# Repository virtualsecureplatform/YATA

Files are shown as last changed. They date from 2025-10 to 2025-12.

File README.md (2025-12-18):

This repository is the artifact for the TCHES2026 paper; YATA: Yet Another TFHE Accelerator with Key Compression and Radix-8 NTT

# Directories
- YATA-RTL: RTL codes excluding NDA related things like SRAM IP and PLL. This also contains RTL-level simulations and some Python scripts we used for the design. 
- YATA-PCB: The KiCAD project for the evaluation board.
- YATA-script: Test\&Measurement and making graph scripts, we used to make the evaluation section of our paper. This also contains Equipment.md, the description of the measurement equipment we used.

# LICENSE
RTL is basically licensed under AGPLv3, except for the AsyncQueue, which originated from Rocketchip. 

PCB and scripts are under MIT. 

# Quick Start For Artifact Reviewers
Since reproducing our evaluation entirely requires physical access to our fabricated chip, we only hope to ensure the availability of our artifact. 

## Cloning
Because YATA-RTL includes subprojects, please clone with `--recursive` flag like:

`git clone --recursive https://github.com/virtualsecureplatform/YATA.git`

## YATA-RTL
For 'YATA-RTL', you can find our RTL codes under 'chise/src/main/'. 
To compile our Chisel3 code to Verilog and run tests with Verilator, please install Apptainer or Singularity, then build and run yata-rtl.def. 

## YATA-PCB
You can open the design using KiCAD 9 or later. We also provide the required footprint library under `Library.pretty` and the Gerber file under `jlcpcb`. We believe that if the reviewer can open the design and check the availability of libraries and gerber file, it is enough. 

## YATA-script
Though the main script, `oneshottest.py`, is included,  this requires all the equipment we used to check executability. Hence, we believe just checking the availability is enough. 
`testvectors` includes some data required for measurement using `oneshottest.py`, like input ciphertexts and evaluation keys. 

The important part is that `logs` directory includes our measured data compressed in bzip2. If you installed bzip2 on your machine, running `decompress_pickles.sh` decompresses them.  
After decompression, by running `measured_plot.py`, you can reproduce our Fig. 4 and 6. Because we retouched Figure 6 for readability, you may notice some differences, but this is expected.

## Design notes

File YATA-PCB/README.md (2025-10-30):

This PCB is designed using KiCAD 9. 
For assembly, most of the parts can be purchased from DigiKey or Mouser, but SMA connectors and probe sockets are purchased from a local Japanese store. 

https://akizukidenshi.com/catalog/g/g101422/

https://akizukidenshi.com/catalog/g/g115480/

I recommend replacing them with your favorite ones if you plan to reuse this PCB design. 
There is a sense register for measuring current, but we did not use it because the noise seems too high. 

`Library.pretty` includes some libraries we prepared for our PCB, so you have to configure path for them. 

`jlcpcb` includes the Gerber file we used to order our PCB from JLCPCB.

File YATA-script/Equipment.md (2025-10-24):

# Measurement Settings
This subsection outlines the measurement settings, including the equipment, voltage settings, and procedure we used for our evaluation.

---
## Equipment

The experimental setup used a Raspberry Pi 5 as the host computer, which communicated with the YATA chip via SPI and GPIO interfaces.
A Texas Instruments SN74AXC4T774-Q1 level shifter was used on the test board to interface the Raspberry Pi's 3.3 V I/O with YATA's 1.8 V I/O.

Power was supplied by KeySight E36233A (for the compute core and PLL) and E3631A (for I/O pins).
To ensure accurate voltage delivery to the compute core despite observed on-chip voltage drop, the E36233A's remote sense feature was connected to an on-chip sense point.

Measurements were performed using the following instruments:
* **Voltage & Current:** KeySight 34465A for monitoring core supply voltage, and Tektronix DMM7510 for measuring core current with 1 µs interval.
* **Latency:** KeySight 53230A Time Interval Counter measured latency, which is defined as the time from the start of the SPI 'RUN' command's SCLK to the assertion of the *fin* signal.
* **Frequency:** A KeySight 53132A Frequency Counter monitored the divided PLL clock frequency (PLLCLK\_DIV).
* **Reference clock:** A Teledyne LeCroy WaveStation 2052 provided a 20 MHz reference clock.

The Raspberry Pi 5 automated the entire experiment, via standard instrument interfaces (LXI, USB, and GPIB using a [UsbGpib](https://github.com/xyphro/UsbGpib) adapter). Instrument control and data acquisition were managed using PyVISA.

---
## Voltage Settings

Nominal operating voltages for YATA chip are: $0.9\,\text{V}$ for the compute core, $0.8\,\text{V}$ for the PLL, and $1.8\,\text{V}$ for I/O.
To explore frequency and stability trade-offs, we varied the core and PLL voltages:
PLL voltage was increased to $0.9\,\text{V}$ when operating above $340\,\text{MHz}$ for improved PLL stability.
Core voltage was swept from $0.8\,\text{V}$ to $0.94\,\text{V}$ in $0.1\,\text{V}$ steps. The upper limit was chosen as the highest voltage without causing degradation or thermal damage to the chip.

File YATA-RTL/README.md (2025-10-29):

# YATA-RTL

This project provides a Singularity container for building and testing the RTL coedes for YATA, which includes Chisel hardware design, Verilator simulation, and TFHEpp cryptographic library integration.

## Overview

The YATA-RTL project combines:
- **Chisel** - Hardware construction language embedded in Scala
- **Verilator** - Fast free Verilog HDL simulator
- **TFHEpp** - C++ implementation of TFHE (Fast Fully Homomorphic Encryption over the Torus)
- **CMake/Ninja** - Modern build system with Clang/LLD toolchain

## Project Structure

```
YATA-RTL/
├── chisel/                   # Chisel hardware designs
│   ├── src/
│   │   ├── main/scala/       # Chisel source files
│   │   └── test/cpp/         # C++ test files
│   ├── build.sbt             # Scala build configuration
│   └── CMakeLists.txt
├── thirdparties/
│   ├── ascon-hardware/       # ASCON's reference implementation for testing 
│   └── TFHEpp/               # TFHE library for CPU
├── CMakeLists.txt            # Top-level CMake config
├── yata-rtl.def              # Singularity definition file
├── python/                   # Python scripts we used for determing some design decisions 
└── README.md                 # This file
```

### Chisel Source Files (`chisel/src/main/scala/`)

#### Core Configuration
- **`Config.scala`** - Central configuration file defining all TFHE parameters (security parameters n, N, k, l), hardware settings (bus widths, memory depths), NTT parameters, and arithmetic constants for the cryptographic operations.

#### Cryptographic Core Modules
- **`BlindRotate.scala`** - Implements TFHE blind rotation operation with test vector rotation and memory management. Contains `RotatedTestVector` for generating rotated test polynomials and `BlindRotateMemory` for efficient storage and access of blind rotation data.

- **`ExternalProduct.scala`** - Performs external product operations for TFHE. Includes `Decomposition` module that decomposes ciphertexts into digits.

- **`KeyCompression.scala`** - Handles bootstrapping key compression using PRNG-based techniques. Integrates multiple ASCON PRNG instances to generate compressed bootstrapping keys with reduced storage requirements.

- **`PolynomialMulByXai.scala`** - Implements polynomial multiplication by X^ai operation, a critical component in TFHE polynomial arithmetic for rotating polynomials by arbitrary amounts.

#### NTT and Arithmetic Modules
- **`NTT.scala`** - Number Theoretic Transform implementation with `DoubleLbuffer` for efficient double buffering and pipelined NTT operations supporting high-throughput polynomial multiplication.

- **`INTorus.scala`** - Arithmetic operations over modulo P. Includes `INTorusADD`, `INTorusSUB`, and `INTorusSREDC` for addition, subtraction, and Montgomery reduction.

- **`ButterflyADD.scala`** - Butterfly operations for NTT/INTT computations. Contains `ButterflyBothMod` and `ButterflyAddMod` for parallel addition and subtraction used in NTT butterflies.

#### Random Number Generation
- **`xoshiro.scala`** - Xoshiro128++ PRNG implementation for generating pseudorandom numbers with 128-bit state, used for non-nonce part of the evaluation key in TFHE.

- **`ascon.scala`** - ASCON cryptographic permutation components including S-box (`ASCONSbox`), linear layer (`ASCONLinear`), and full permutation (`ASCONPermuitation`) for PRNG operations.

#### Communication Interfaces
- **`AXI4.scala`** - AXI4 and AXI4-Stream interface definitions. Includes `AXI4Manager`, `AXI4StreamManager`, and `AXI4StreamSubordinate` for standard AMBA communication protocols.

- **`SPI.scala`** - SPI interface for configuration and control. Contains `SPIConfigModule` for runtime parameter configuration and status monitoring via SPI protocol.

- **`ChangeSizer.scala`** - Data width conversion modules. Includes `UpSizer` and `DownSizer` for converting between different bus widths in the data path.

#### AsyncQueue (Clock Domain Crossing, From RocketChip)
- **`AsyncQueue/AsyncQueue.scala`** - Main asynchronous FIFO queue for safe clock domain crossing with configurable depth and synchronization stages.

- **`AsyncQueue/AsyncResetReg.scala`** - Reset synchronization primitives for handling reset signals across clock domains.

- **`AsyncQueue/SynchronizerReg.scala`** - Register-based synchronizers for CDC (Clock Domain Crossing) with configurable synchronization stages.

- **`AsyncQueue/Crossing.scala`** - High-level crossing utilities combining AsyncQueue with other CDC primitives.

- **`AsyncQueue/ShiftReg.scala`** - Shift register implementations for delay lines and synchronization.

- **`AsyncQueue/Counter.scala`** - Gray code counters for AsyncQueue pointer management across clock domains.

- **`AsyncQueue/BundleMap.scala`** - Utilities for mapping bundles across AsyncQueue interfaces.

- **`AsyncQueue/CompileOptions.scala`** - Compilation options and parameters for AsyncQueue modules.

- **`AsyncQueue/package.scala`** - Package object with utility functions and implicit conversions for AsyncQueue.

#### Utility Modules
- **`Util.scala`** - Memory utility components including `RWSmem` (single-port SRAM), `WFTPSAmem` (write-first two-port SRAM), and `RWDmem` (dual-port SRAM) for various memory access patterns.

## Prerequisites

- Singularity/Apptainer installed on your system
- Sudo access (sometimes required for building the container)
- At least 2GB of free disk space

### Installing Apptainer

On Ubuntu/Debian:
```bash
sudo apt-get update
sudo add-apt-repository -y ppa:apptainer/ppa
sudo apt update
sudo apt-get install -y apptainer
```

For other systems, see [Apptainer Installation Guide](https://apptainer.org/docs/admin/main/installation.html).

## Building the Container

Build the Singularity container from the definition file:

```bash
sudo singularity build yata-rtl.sif yata-rtl.def
```

This process takes approximately 10-15 minutes and will:
- Install Ubuntu 24.04 base system
- Install Java and sbt (Scala Build Tool)
- Install CMake 3.31+ from Kitware
- Build Verilator 5.x from source
- Install Clang, LLD, Ninja, and other build tools
- Install TFHEpp dependencies

The resulting container image (`yata-rtl.sif`) will be approximately 987MB.

## Usage

### Running the Full Build Pipeline

Execute the complete build and test pipeline:

```bash
singularity run --bind $(pwd):/home/ubuntu/sources/YATA/YATA-RTL yata-rtl.sif
```

This will:
1. Run `sbt` to compile Chisel/Scala code and generate Verilog
2. Configure the project with CMake
3. Build with Ninja
4. Execute the test program

### Running Individual Commands

Execute specific commands inside the container:

```bash
# Run sbt only
singularity exec --bind $(pwd):/home/ubuntu/sources/YATA/YATA-RTL yata-rtl.sif \
  bash -c "cd /home/ubuntu/sources/YATA/YATA-RTL/chisel && sbt run"

# Build with CMake and Ninja
singularity exec --bind $(pwd):/home/ubuntu/sources/YATA/YATA-RTL yata-rtl.sif \
  bash -c "cd /home/ubuntu/sources/YATA/YATA-RTL && cmake . -B build -G Ninja -DCMAKE_CXX_COMPILER=clang++ -DCMAKE_C_COMPILER=clang -DCMAKE_LINKER_TYPE=LLD && cd build && ninja"

# Run tests
singularity exec --bind $(pwd):/home/ubuntu/sources/YATA/YATA-RTL yata-rtl.sif \
  bash -c "cd /home/ubuntu/sources/YATA/YATA-RTL/build && ./chisel/src/test/cpp/cpptest"
```

### Interactive Shell

Launch an interactive shell inside the container:

```bash
singularity shell --bind $(pwd):/home/ubuntu/sources/YATA/YATA-RTL yata-rtl.sif
```

## Container Contents

The container includes:

### Build Tools
- **CMake** 3.31+ (from Kitware repository)
- **Ninja** build system
- **Clang** 18.1.3 (C/C++ compiler)
- **LLD** (LLVM linker)
- **GCC** 13 (GNU compiler collection)

### Development Tools
- **Java** 11 (OpenJDK)
- **sbt** 1.11.7 (Scala Build Tool)
- **Verilator** 5.040 (built from source)
- **Git**

### Libraries
- **TFHEpp** dependencies:
- **Verilator** dependencies

## Build Output

After a successful build, you will find:

- **Generated Verilog**: `chisel/AXISBRWrapper.v`
- **Build directory**: `build/` (contains all compiled objects)
- **Test executable**: `build/chisel/src/test/cpp/cpptest` (~43MB)
- **Static libraries**:
  - `build/thirdparties/TFHEpp/src/libtfhe++.a`
  - `build/thirdparties/TFHEpp/thirdparties/randen/libranden.a`
  - `build/thirdparties/TFHEpp/thirdparties/spqlios/libspqlios.a`

## Troubleshooting

### Container Build Fails

If the container build fails:
1. Ensure you have sudo access
2. Check available disk space (`df -h`)
3. Try cleaning up old containers: `singularity cache clean`

### sbt Compilation Warnings

Deprecation warnings from Chisel 3.6 are expected and do not affect functionality. The project uses Chisel 3.6 compatibility layer.

### Linker Warnings

Warnings about `_ExtInt` being deprecated are from TFHEpp and do not affect the build.

### Permission Issues

If you encounter permission errors, ensure the bind mount path is correct and accessible:
```bash
singularity exec --bind $(pwd):/home/ubuntu/sources/YATA/YATA-RTL yata-rtl.sif ls -la /home/ubuntu/sources/YATA/YATA-RTL
```

## Development Workflow

1. **Modify Chisel sources** in `chisel/src/main/scala/`
2. **Generate Verilog**:
   ```bash
   singularity exec --bind $(pwd):/home/ubuntu/sources/YATA/YATA-RTL yata-rtl.sif \
     bash -c "cd /home/ubuntu/sources/YATA/YATA-RTL/chisel && sbt run"
   ```
3. **Build and test**:
   ```bash
   singularity run --bind $(pwd):/home/ubuntu/sources/YATA/YATA-RTL yata-rtl.sif
   ```

## Performance Notes

- **First build**: Takes ~5-10 minutes (compiles Scala, generates Verilog, compiles C++)
- **Incremental builds**: Much faster, only recompiles changed files
- **Parallel compilation**: Verilator uses 12 threads, Ninja uses all available cores

## License

See the LICENSE file for license information.

## References

- [Chisel](https://www.chisel-lang.org/) - Hardware construction language
- [Verilator](https://verilator.org/) - Fast Verilog simulator
- [TFHEpp](https://github.com/virtualsecureplatform/TFHEpp) - TFHE implementation
- [Singularity](https://sylabs.io/singularity/) - Container platform

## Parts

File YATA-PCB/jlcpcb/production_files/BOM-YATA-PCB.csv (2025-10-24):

Comment | Designator | Footprint | LCSC
ICDC | J4 | AMASS_XT30PW-M_1x02_P2.50mm_Horizontal
4u7 | C10 | CAPC0610X45N
4u7 | C3 | CAPC0610X45N
dividedclk | J6 | Akizuki-SMA
4u7 | C28 | CAPC0610X45N
ControlSPI | J1 | JST_XH_B6B-XH-A_1x06_P2.50mm_Vertical
Conn_01x01 | J9 | MountingHole_3.2mm_M3_ISO7380_Pad
4u7 | C29 | CAPC0610X45N
4u7 | C37 | CAPC0610X45N
4u7 | C5 | CAPC0610X45N
4u7 | C17 | CAPC0610X45N
220u | C2 | C_1210_3225Metric_Pad1.33x2.70mm_HandSolder
4u7 | C21 | CAPC0610X45N
1000u | C11 | CP_Elec_10x10
4u7 | C27 | CAPC0610X45N
4u7 | C24 | CAPC0610X45N
4u7 | C18 | CAPC0610X45N
4u7 | C22 | CAPC0610X45N
4u7 | C4 | CAPC0610X45N
4u7 | C13 | CAPC0610X45N
SN74AXC4T774QPWRQ1 | IC2 | SOP65P640X120-16N
220u | C45 | C_1210_3225Metric_Pad1.33x2.70mm_HandSolder
4u7 | C19 | CAPC0610X45N
Conn_01x01 | J10 | MountingHole_3.2mm_M3_ISO7380_Pad
IC149-100-014-B5 | J8 | IC149-100-014-B5
SN74AXC4T774QPWRQ1 | IC1 | SOP65P640X120-16N
4u7 | C33 | CAPC0610X45N
4u7 | C6 | CAPC0610X45N
4u7 | C16 | CAPC0610X45N
4u7 | C9 | CAPC0610X45N
GPIO | J3 | JST_XH_B5B-XH-A_1x05_P2.50mm_Vertical
4u7 | C30 | CAPC0610X45N
ConfigureSPI | J2 | JST_XH_B6B-XH-A_1x06_P2.50mm_Vertical
4u7 | C42 | CAPC0610X45N
IODC | J13 | AMASS_XT30PW-M_1x02_P2.50mm_Horizontal
Conn_01x01 | J12 | MountingHole_3.2mm_M3_ISO7380_Pad
4u7 | C34 | CAPC0610X45N
4u7 | C23 | CAPC0610X45N
SN74AXC4T774QPWRQ1 | IC3 | SOP65P640X120-16N
4u7 | C26 | CAPC0610X45N
Conn_01x01 | J11 | MountingHole_3.2mm_M3_ISO7380_Pad
4u7 | C20 | CAPC0610X45N
4u7 | C32 | CAPC0610X45N
PLLDC | J7 | AMASS_XT30PW-M_1x02_P2.50mm_Horizontal
4u7 | C25 | CAPC0610X45N
4u7 | C39 | CAPC0610X45N
clock | J5 | Akizuki-SMA
1000u | C44 | CP_Elec_10x10
220u | C8 | C_1210_3225Metric_Pad1.33x2.70mm_HandSolder
4u7 | C12 | CAPC0610X45N
4u7 | C31 | CAPC0610X45N
4u7 | C43 | CAPC0610X45N
4u7 | C14 | CAPC0610X45N
1000u | C1 | CP_Elec_10x10
4u7 | C15 | CAPC0610X45N
4u7 | C38 | CAPC0610X45N
4u7 | C40 | CAPC0610X45N
4u7 | C35 | CAPC0610X45N
4u7 | C36 | CAPC0610X45N
4u7 | C7 | CAPC0610X45N
4u7 | C41 | CAPC0610X45N

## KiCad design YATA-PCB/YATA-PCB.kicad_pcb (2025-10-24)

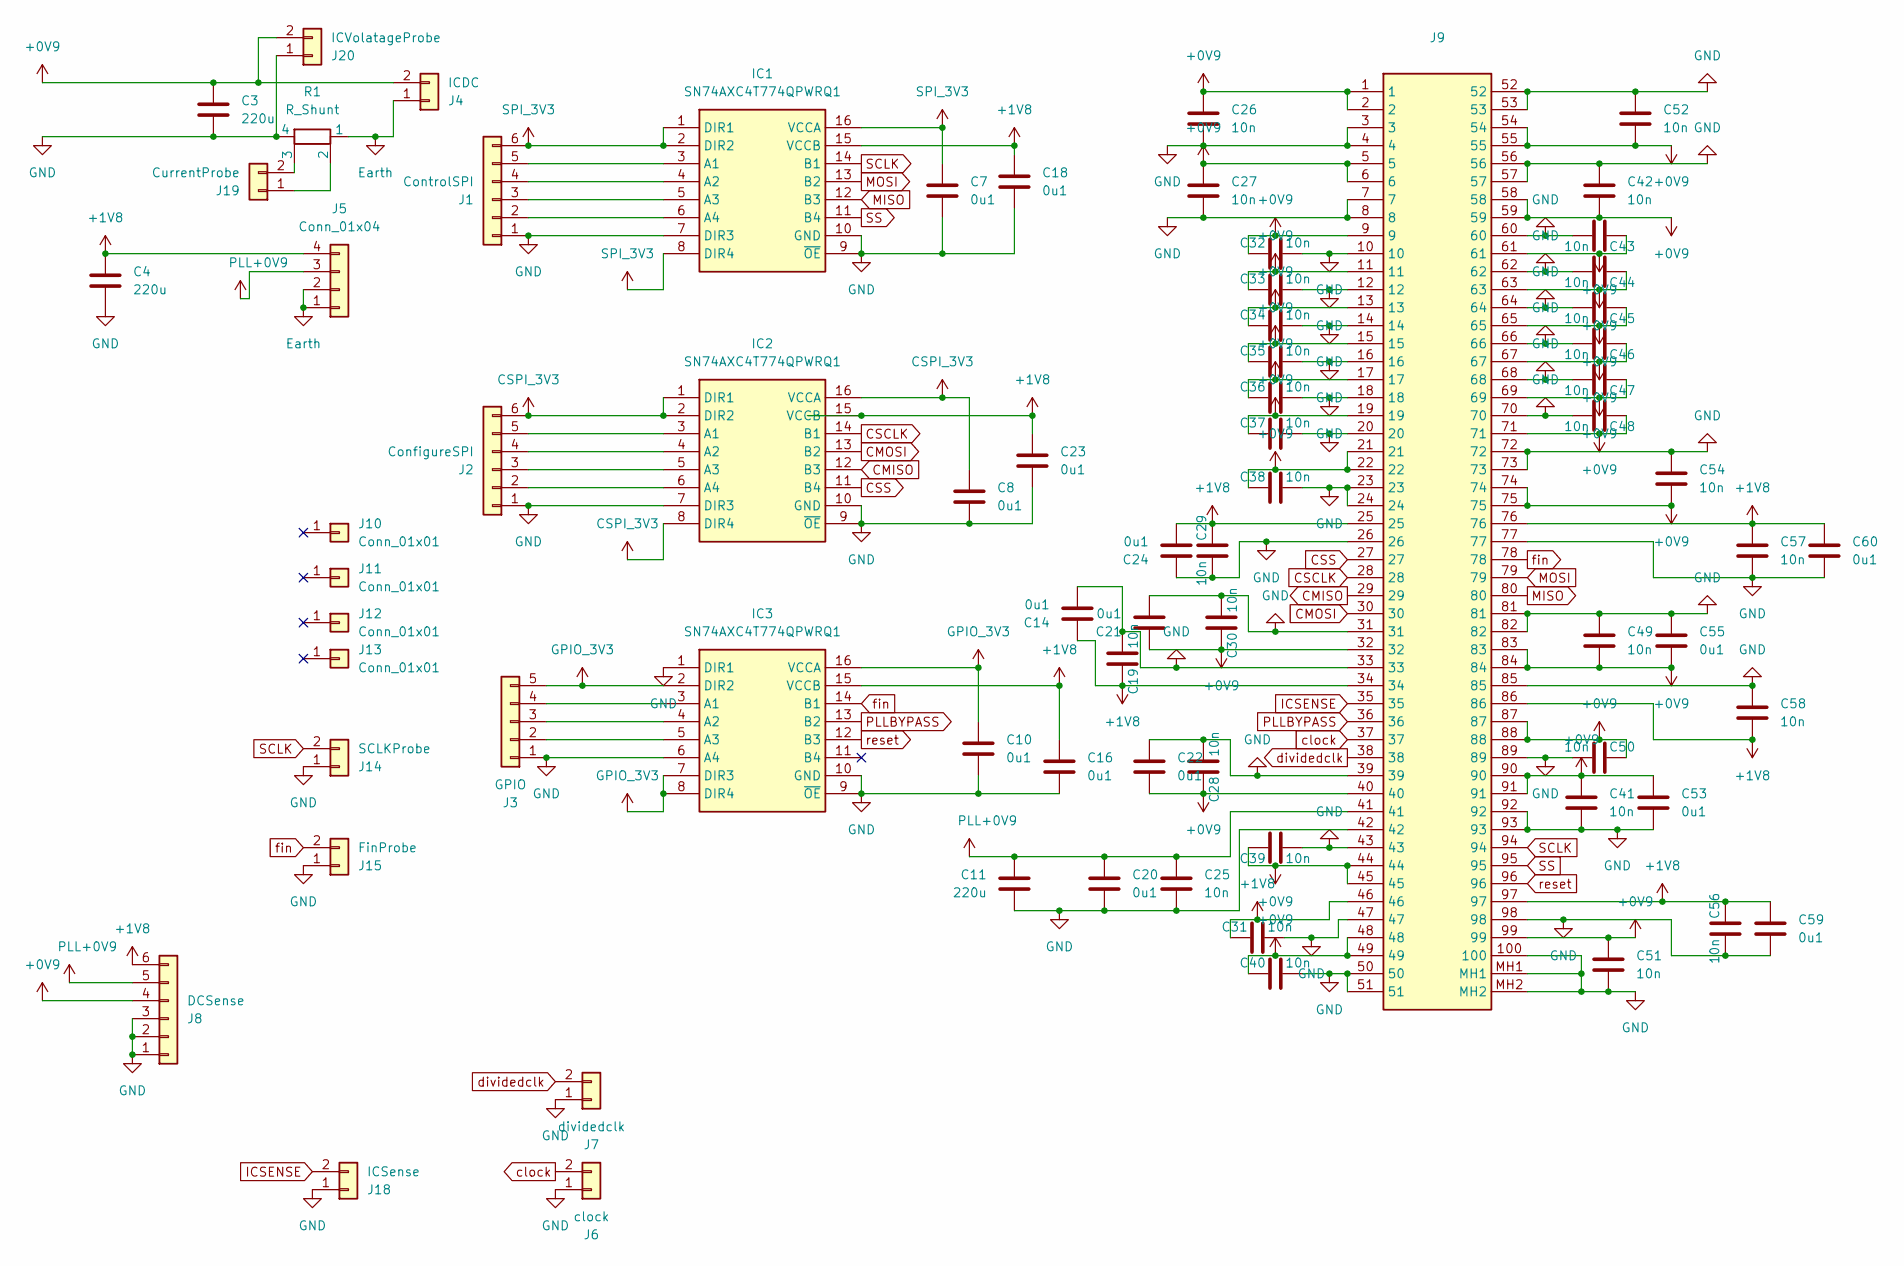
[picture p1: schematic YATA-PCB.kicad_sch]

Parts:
C3, C4, C11: 220u; C_1210_3225Metric_Pad1.33x2.70mm_HandSolder
C7, C8, C10, C14, C16, C18, C20, C21, C22, C23, C24, C53, C55, C59, C60: 0u1; C_0402_1005Metric
C19, C25, C26, C27, C28, C29, C30, C31, C32, C33, C34, C35, C36, C37, C38, C39, C40, C41, C42, C43, C44, C45, C46, C47, C48, C49, C50, C51, C52, C54, C56, C57, C58: 10n; C_0201_0603Metric_Pad0.64x0.40mm_HandSolder
IC1, IC2, IC3: SN74AXC4T774QPWRQ1; SOP65P640X120-16N; Manufacturer_Part_Number SN74AXC4T774QPWRQ1; Mouser Part Number 595-74AXC4T774QPWRQ1
J1: ControlSPI; JST_XH_B6B-XH-A_1x06_P2.50mm_Vertical
J2: ConfigureSPI; JST_XH_B6B-XH-A_1x06_P2.50mm_Vertical
J3: GPIO; JST_XH_B5B-XH-A_1x05_P2.50mm_Vertical
J4: ICDC; AMASS_XT30PW-M_1x02_P2.50mm_Horizontal
J5: Conn_01x04; JST_XA_B04B-XASK-1_1x04_P2.50mm_Vertical
J6: clock; Akizuki-SMA
J7: dividedclk; PA013
J8: DCSense; JST_XA_B06B-XASK-1_1x06_P2.50mm_Vertical
J9: IC149-100-014-B5; Manufacturer_Part_Number IC149-100-014-B5; Mouser Part Number 945-IC149-100-014-B5
J10, J11, J12, J13: Conn_01x01; MountingHole_3.2mm_M3_ISO7380_Pad
J14: SCLKProbe; PA013
J15: FinProbe; PA013
J18: ICSense; JST_XA_B02B-XASK-1_1x02_P2.50mm_Vertical
J19: CurrentProbe; PA013
J20: ICVolatageProbe; PA013
R1: R_Shunt; Y14870R01000B9R

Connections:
+0V9: C3.1, C21.1, C22.2, C26.1, C27.1, C28.1, C30.1, C32.1, C33.1, C34.1, C35.1, C36.1, C37.1, C38.1, C39.1, C40.1, C41.1, C42.2, C43.1, C44.1, C45.1, C46.1, C47.1, C48.1, C49.2, C50.1, C51.1, C52.2, C53.1, C54.2, C55.2, J4.2, J8.4, J9.1, J9.2, J9.5, J9.6, J9.9, J9.11, J9.13, J9.15, J9.17, J9.19, J9.21, J9.22, J9.32, J9.40, J9.44, J9.45, J9.48, J9.49, J9.54, J9.55, J9.58, J9.59, J9.61, J9.63, J9.65, J9.67, J9.69, J9.71, J9.74, J9.75, J9.83, J9.84, J9.87, J9.88, J9.90, J9.91, J9.99, J20.2
+1V8: C4.1, C14.1, C16.1, C18.1, C19.1, C23.1, C24.2, C29.1, C31.1, C56.1, C57.1, C58.2, C59.1, C60.1, IC1.15 (VCCB), IC2.15 (VCCB), IC3.15 (VCCB), J5.4, J8.6, J9.25, J9.34, J9.46, J9.76, J9.86, J9.97
CMISO: IC2.12 (B3), J9.29
CMOSI: IC2.13 (B2), J9.30
CSCLK: IC2.14 (B1), J9.28
CSPI_3V3: C8.1, IC2.1 (DIR1), IC2.2 (DIR2), IC2.8 (DIR4), IC2.16 (VCCA), J2.6
CSS: IC2.11 (B4), J9.27
Earth: J4.1, J5.1, J5.2, R1.1
GND: C3.2, C4.2, C7.2, C8.2, C10.2, C11.2, C14.2, C16.2, C18.2, C19.2, C20.2, C21.2, C22.1, C23.2, C24.1, C25.2, C26.2, C27.2, C28.2, C29.2, C30.2, C31.2, C32.2, C33.2, C34.2, C35.2, C36.2, C37.2, C38.2, C39.2, C40.2, C41.2, C42.1, C43.2, C44.2, C45.2, C46.2, C47.2, C48.2, C49.1, C50.2, C51.2, C52.1, C53.2, C54.1, C55.1, C56.2, C57.2, C58.1, C59.2, C60.2, IC1.7 (DIR3), IC1.9 (~OE), IC1.10 (GND), IC2.7 (DIR3), IC2.9 (~OE), IC2.10 (GND), IC3.1 (DIR1), IC3.6 (A4), IC3.9 (~OE), IC3.10 (GND), J1.1, J2.1, J3.1, J6.1, J7.1, J8.1, J8.2, J8.3, J9.3, J9.4, J9.7, J9.8, J9.10, J9.12, J9.14, J9.16, J9.18, J9.20, J9.23, J9.24, J9.26, J9.31, J9.33, J9.39, J9.42, J9.43, J9.47, J9.50, J9.51, J9.52, J9.53, J9.56, J9.57, J9.60, J9.62, J9.64, J9.66, J9.68, J9.70, J9.72, J9.73, J9.77, J9.81, J9.82, J9.85, J9.89, J9.92, J9.93, J9.98, J9.100, J9.MH1, J9.MH2, J14.1, J15.1, J18.1, J20.1, R1.4
GPIO_3V3: C10.1, IC3.2 (DIR2), IC3.7 (DIR3), IC3.8 (DIR4), IC3.16 (VCCA), J3.5
ICSENSE: J9.35, J18.2
MISO: IC1.12 (B3), J9.80
MOSI: IC1.13 (B2), J9.79
unnamed: IC1.3 (A1), J1.5
unnamed: IC1.4 (A2), J1.4
unnamed: IC1.5 (A3), J1.3
unnamed: IC1.6 (A4), J1.2
unnamed: IC2.3 (A1), J2.5
unnamed: IC2.4 (A2), J2.4
unnamed: IC2.5 (A3), J2.3
unnamed: IC2.6 (A4), J2.2
unnamed: IC3.3 (A1), J3.4
unnamed: IC3.4 (A2), J3.3
unnamed: IC3.5 (A3), J3.2
unnamed: J19.1, R1.2
unnamed: J19.2, R1.3
PLL+0V9: C11.1, C20.1, C25.1, J5.3, J8.5, J9.41
PLLBYPASS: IC3.13 (B2), J9.36
SCLK: IC1.14 (B1), J9.94, J14.2
SPI_3V3: C7.1, IC1.1 (DIR1), IC1.2 (DIR2), IC1.8 (DIR4), IC1.16 (VCCA), J1.6
SS: IC1.11 (B4), J9.95
clock: J6.2, J9.37
dividedclk: J7.2, J9.38
fin: IC3.14 (B1), J9.78, J15.2
reset: IC3.12 (B3), J9.96

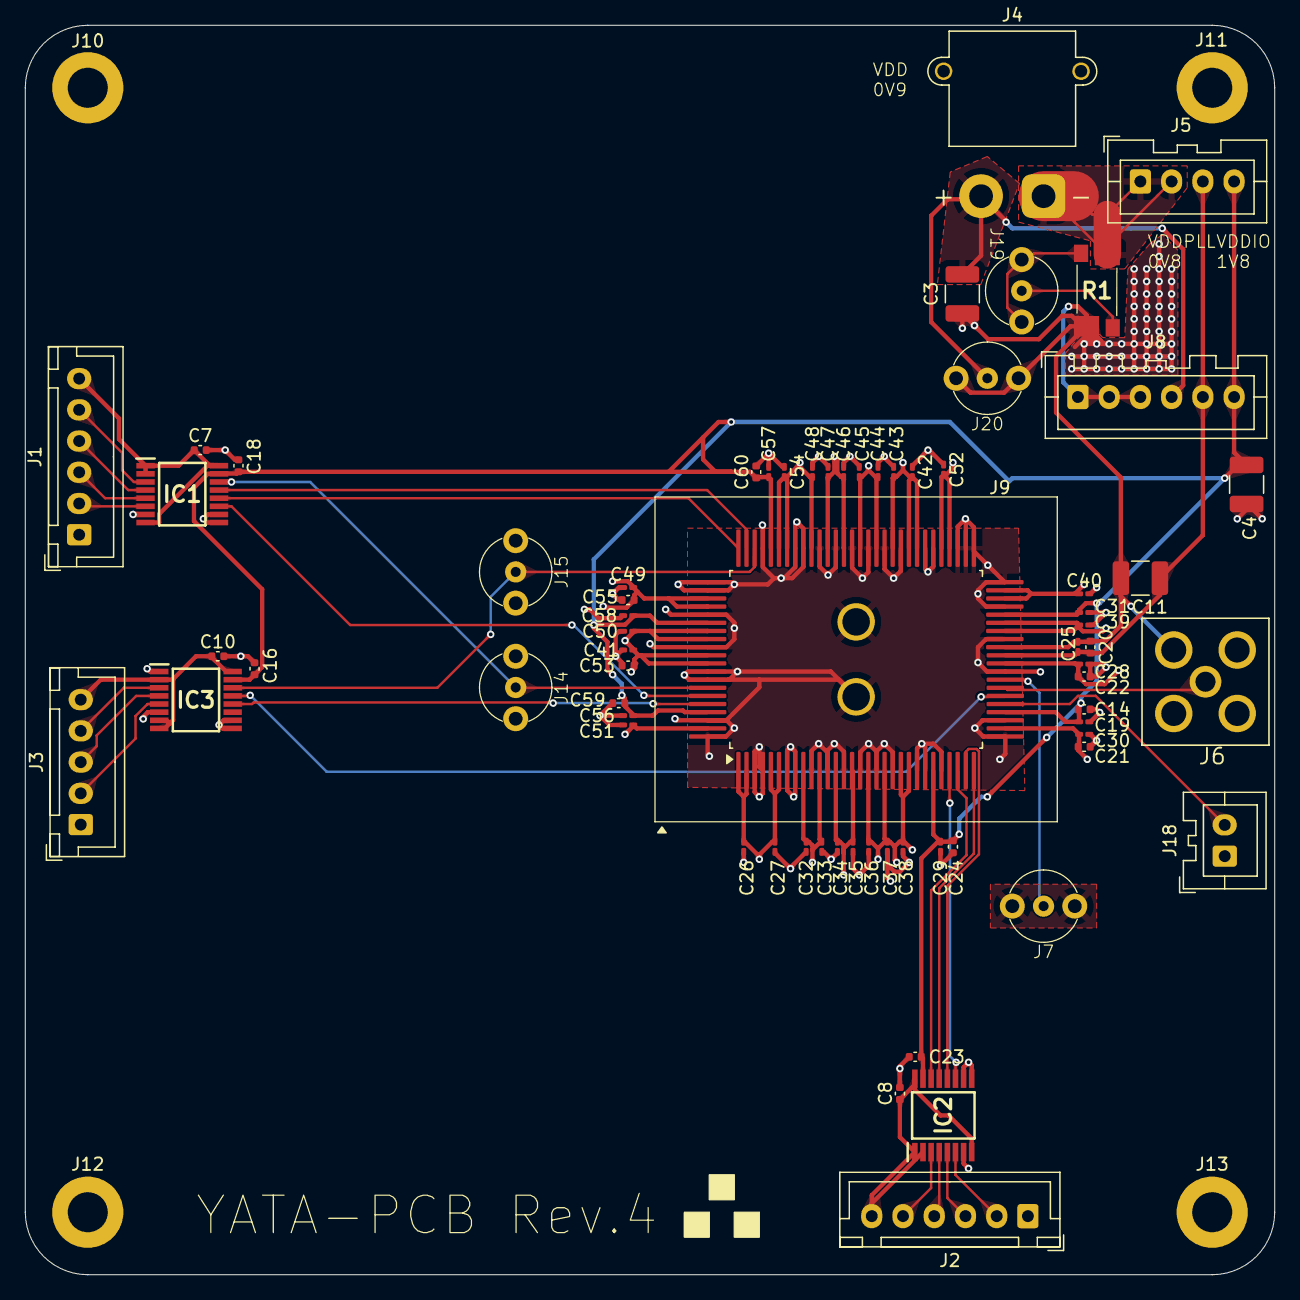
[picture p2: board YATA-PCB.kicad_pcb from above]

Board: 4 copper layers, 100.0 x 100.0 mm, 73 parts (0 on the bottom side), 35 nets.

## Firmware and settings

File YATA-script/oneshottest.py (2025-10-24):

#!/bin/bash

def reverse_byte(a):
    return ((a & 0x1) << 7) | ((a & 0x2) << 5) | \
           ((a & 0x4) << 3) | ((a & 0x8) << 1) | \
           ((a & 0x10) >> 1) | ((a & 0x20) >> 3) | \
           ((a & 0x40) >> 5) | ((a & 0x80) >> 7)

def repeat_reconstruct(ret):
    ret_rev = [reverse_byte(x) for x in ret]
    val = ret_rev[0]>>4
    for i in range(8):
        val = val + (ret_rev[i+1]<<(4+8*i))
    val_str = str(hex(val))[2:].zfill(16)
    return [reverse_byte(int(val_str[x:x+2],16)) for x in range(0, len(val_str), 2)][::-1]

maxpower = 0
compress = 0b000

clkfreq = int(2e7)
spifreq = clkfreq//4

def config_bytes(PLLCOARSEDELAYBINARY_CODE, PLLMMDCLKDIV_RATIO, PIgain, reset =True):
    PLLRESET = 0 # Active_low
    PLLDLF_Clear = 1 #1'b1 clear PID data, 1'b0 do nothing. this signal is inferior to reset.
    PLLDLF_En = 1 # 1'b1 Enable   1'b1 Disable of PID

    # 1'b1: using external PID value from port PLLDLF_Ext_Data  1'b0: using internal signal
    # Note that if you set this signal 1, the PLLDLF_En should be set to 0８
    PLLDLF_Ext_Override = 0
    PLLDLF_IN_POL = 1 # the polarity of control signal. + -

    PLLRC = 0 #DLF RC Value
    PLLDLF_Ext_Data = 0 # set internal DLF State

    PLLDLF_KI = PIgain["I"]# PLL I gain, hand tuned
    PLLDLF_KP = PIgain["P"]# PLL P gain hand tuned 

    PLLOUT_CLKDIV_RATIO = 0

    if(not reset):
        PLLRESET = 1
        PLLDLF_Clear = 0
        PLLRC = 0b111

    config_str=(f"{PLLOUT_CLKDIV_RATIO:08b}"+f"{PLLCOARSEDELAYBINARY_CODE:07b}"+f"{PLLMMDCLKDIV_RATIO:08b}"+f"{PLLDLF_KP:04b}"+f"{PLLDLF_KI:04b}"+f"{PLLDLF_Ext_Data:010b}"+f"{PLLRC:03b}"+f"{PLLDLF_IN_POL:01b}"+f"{PLLDLF_Ext_Override:01b}"+f"{PLLDLF_En:01b}"+f"{PLLDLF_Clear:01b}"+f"{PLLRESET:01b}"+f"{compress:03b}"+f"{maxpower:01b}")
    config_str = config_str.zfill(64)
    # config_str = 11*"1"+ config_str
    # return [reverse_byte(int(config_str[x:x+8],2)) for x in range(0, len(config_str), 8)]+[0x0]
    config_array=[reverse_byte(int(config_str[x:x+8],2)) for x in range(0, len(config_str), 8)]
    config_array.reverse()
    return config_array

import pickle

bkraintt_bytes = []

nstep = 2

lvl1k = 2
lvl1l = 2
lvl1N = 512
lvl0n = 636

wordbits = 27
nttwordsinbus = 512//32
bknumbus = 12
numcycle = 8

cmd_seed = 0b10100000;
cmd_bkfifo0 = 0b10101100
cmd_bkfifo1 = 0b10101101
cmd_bkfifo2 = 0b10101110
cmd_bkfifo = [cmd_bkfifo0,cmd_bkfifo1,cmd_bkfifo2]
cmd_infifo = 0b10110000;
cmd_run = 0b11110000;
cmd_runstep = 0b11100000
cmd_out = 0b10000000;
cmd_flush = 0b11000000;

import gpiozero
import time
import spidev
import pyvisa
import random
import sys

rm = pyvisa.ResourceManager()
powersupply = rm.open_resource('TCPIP::10.0.20.72::INSTR')
vddio = rm.open_resource('USB0::1003::8293::HEWLETT-PACKARD_E3631A_0_3.0-6.0-2.0::0::INSTR')

functiongenerator = rm.open_resource('USB0::1535::2593::LCRY2362C01679::0::INSTR')
functiongenerator.write('C1:BSWV WVTP,SQUARE,AMP,0.9,OFST,0.9,FRQ,'+str(clkfreq))

diffcounter = rm.open_resource('TCPIP::10.0.20.78::INSTR')
diffcounter.write("*RST; *CLS")
diffcounter.write("INPut1:COUPling DC")
diffcounter.write("INPut2:COUPling DC")
diffcounter.write("CONF:TINT (@1), (@2)")
diffcounter.write("INP1:RANG 50")
diffcounter.write("INP2:RANG 50")
diffcounter.write("INPut1:PROBe 10")
diffcounter.write("INPut2:PROBe 10")
diffcounter.write("INP:LEV .9")
diffcounter.write("INPut2:LEVel 0.9")
diffcounter.write("SAMP:COUN 1")

freqcounter = rm.open_resource('USB0::1003::8293::HEWLETT-PACKARD_53132A_0_4613::0::INSTR')
freqcounter.timeout = 5000
freqcounter.write("*RST; *CLS; *SRE 0; *ESE 0; :STAT:PRES")
freqcounter.write("EVENt1:LEVel:AUTO OFF")
freqcounter.write("EVENt1:LEVel 0.09")
freqcounter.write(":INPut1:COUPling DC")
freqcounter.write(":FUNC 'FREQ 1'")
freqcounter.write(":FREQ:ARM:STAR:SOUR IMM")
freqcounter.write(":FREQ:ARM:STOP:SOUR TIM")
freqcounter.write(":FREQ:ARM:STOP:TIM .100")

currentdmm = rm.open_resource('TCPIP::10.0.20.74::INSTR') # DMM7510
currentdmm.timeout = 5000
# currcount = 1000
# currentdmm.write("COUN "+str(currcount))
# currentdmm = rm.open_resource('TCPIP::10.0.20.75::INSTR') # 34456A
# currentdmm.timeout = 5000

# voltagedmm = rm.open_resource('TCPIP::10.0.20.77::INSTR') # 34411A voltage at the VDD connector.
# voltagedmm = rm.open_resource('TCPIP::10.0.20.76::INSTR') # 34410A the inner part of the chip
voltagedmm = rm.open_resource('TCPIP::10.0.20.75::INSTR') # 34465A
voltagedmm.timeout = 5000

# oscilloscope = rm.open_resource('TCPIP::10.0.20.80::INSTR') #T3DSO

spiconf = spidev.SpiDev()
spiconf.open(1,2)
spiconf.max_speed_hz = spifreq
spiconf.mode = 0b00

spiconfdummy = spidev.SpiDev()
spiconfdummy.open(1,1)
spiconfdummy.max_speed_hz = spifreq
spiconfdummy.mode = 0b00

spictrl = spidev.SpiDev()
spictrl.open(0,0)
spictrl.max_speed_hz = spifreq
spictrl.mode = 0b00

resetpin = gpiozero.DigitalOutputDevice(24)
pllbypasspin = gpiozero.DigitalOutputDevice(23)
ctrlcs = gpiozero.DigitalOutputDevice(8)
finpin = gpiozero.DigitalInputDevice(22, pull_up = None, active_state=True)
trigpin = gpiozero.DigitalOutputDevice(27)
trigpin.on()

def turnon(d=0, isPLL0V9=False):
    assert(d<=0.05)
    powersupply.write("*RST; *CLS")
    powersupply.write('APPL CH1, '+str(0.9+d)+',3.6')
    # powersupply.write('APPL CH1, 0.92,3.6')
    if isPLL0V9:
        powersupply.write('APPL CH2, 0.9,0.05')
    else:
        powersupply.write('APPL CH2, 0.8,0.05')
    powersupply.write('VOLT:SENS EXT,(@1)')
    powersupply.write('VOLT:SENS EXT,(@2)')
    powersupply.write('VOLT:PROT 3,(@1)')
    powersupply.write('VOLT:PROT 1.6,(@2)')
    powersupply.write('OUTP ON,(@2)')
    powersupply.write('OUTP ON,(@1)')
    vddio.write("*RST; *CLS")
    vddio.write("APPLy P6V, 1.8, 0.1")
    vddio.write("OUTPut ON")
    functiongenerator.write('C1:OUTP ON')

def turnoff():
    powersupply.write('OUTP OFF,(@1)')
    powersupply.write('OUTP OFF,(@2)')
    vddio.write("OUTPut OFF")
    functiongenerator.write('C1:OUTP OFF')

def spireset():
    ctrlcs.on()

    spiconf.bits_per_word = 10
    spictrl.bits_per_word = 10

    resetpin.on()
    ret = spiconfdummy.xfer([0x0,0x0])
    ret = spictrl.xfer([0x0,0x0])
    resetpin.off()

    ret = spiconfdummy.xfer([0x0,0x0])
    ret = spictrl.xfer([0x0,0x0])

def configuretest():
    spireset()
    to_send = [random.randint(0,255) for x in range(7)]+[random.randint(0,63)*4]
    spiconf.bits_per_word = 8
    ret = spiconf.xfer(to_send.copy())
    print(ret)

    spiconfdummy.bits_per_word = 8
    ret = spiconfdummy.xfer(9*[0x00])
    print([repeat_reconstruct(ret),to_send])
    assert(repeat_reconstruct(ret)==to_send)
    print("CONFIGURE TEST PASS")

sampleratio = 20
currentsample = int(1e5)
voltagesample = int(currentsample/sampleratio)

def PowerMeasureStart():
    trigpin.on()
    voltagedmm.write("*RST; *CLS")
    voltagedmm.query('*OPC?')
    # voltagedmm.write(":SENS:VOLT:DC:APER 1e-5")
    voltagedmm.write("CONF:VOLT:DC 2")
    voltagedmm.write("VOLT:DC:APER MIN")
    # print(voltagedmm.query("VOLT:DC:APER?"))
    # voltagedmm.write("TRIG:SOUR IMM")
    voltagedmm.write("SAMP:COUN "+str(voltagesample))
    # print(voltagedmm.query("SAMP:COUN?"))
    voltagedmm.write("TRIG:SOUR EXT")
    voltagedmm.query('*OPC?')

    # DMM7510
    currentdmm.write("*RST; *CLS")
    currentdmm.write("TRAC:CLE")
    # currentdmm.write('TRAC:MAKE "buffCURR", '+str(currentsample))
    # print(currentdmm.query('TRAC:POIN? "buffCURR"'))
    currentdmm.write('TRAC:POIN '+str(currentsample)+', "defbuffer1"')
    currentdmm.write("TRAC:FILL:MODE ONCE")
    currentdmm.write('DIG:FUNC "CURR"')
    currentdmm.write('DIG:CURR:SRATE 1000000')
    currentdmm.write("DIG:CURR:APER AUTO")
    currentdmm.write("DIG:CURR:RANG 5")
    currentdmm.write("DIG:COUN "+str(currentsample))
    currentdmm.query('*OPC?')
    # 34465A
    # currentdmm.write("*RST; *CLS")
    # currentdmm.query('*OPC?')
    # currentdmm.write("CONF:CURR:DC 10")
    # currentdmm.write("CURR:DC:APER MIN")
    # # print(currentdmm.query("CURR:DC:APER?"))
    # currentdmm.write("SAMP:COUN "+str(currentsample))
    # # currentdmm.write("TRIG:SOUR IMM")
    # currentdmm.write("TRIG:SOUR EXT")
    # currentdmm.query('*OPC?')

    # T3DSO3000HD
    # Reset the oscilloscope and configure waveform data to be returned in double (binary) format.
    # oscilloscope.write("*RST; *CLS")
    # oscilloscope.write(":FORMat:DATA DOUBle")
    # Configure acquisition settings for a high-speed measurement.
    # oscilloscope.write(":ACQuire:AMODe FAST")         # Fast acquisition mode.
    # oscilloscope.write(":ACQuire:SRATe 5.00E9")         # Set sample rate (e.g., 5.00E9 samples/sec).

    # Configure external trigger on the falling (negative) edge.
    # oscilloscope.write(":TRIGger:SOURce EXTernal")      
    # oscilloscope.write(":TRIGger:TYPE EDGE")
    # oscilloscope.write(":TRIGger:EDGE:SLOPe NEGative")   # Specify falling edge trigger.
    # oscilloscope.write(":TRIGger:MODE NORMAL")

    # --- Channel Configurations ---
    # Channel 1: Measures device voltage (expected 0.8 to 1.2 V) using a 10:1 probe.
    # oscilloscope.write(":CHANnel1:PROBe VALue,1.00E+01")  # Configure Channel 1 with a 10:1 probe.
    # oscilloscope.write(":CHANnel1:SCALe 1.00E-01")         # Set vertical sensitivity (e.g., 100 mV/div).
    # oscilloscope.write(":CHANnel1:OFFSet -0.9")            # Subtract 0.9 V by setting an offset of –0.9 V.

    # Channels 2 and 3: Measure voltage across a 100 mΩ sense resistor using 1:1 probes.
    # oscilloscope.write(":CHANnel2:PROBe VALue,1.00E+00")  # Configure Channel 2 with a 1:1 probe.
    # oscilloscope.write(":CHANnel3:PROBe VALue,1.00E+00")  # Configure Channel 3 with a 1:1 probe.
    # oscilloscope.write(":CHANnel2:SCALe 1.00E-01")         # Set vertical sensitivity for Channel 2.
    # oscilloscope.write(":CHANnel3:SCALe 1.00E-01")         # Set vertical sensitivity for Channel 3.
    # oscilloscope.write(":CHANnel2:OFFSet -0.9")            # Subtract 0.9 V by setting an offset of –0.9 V.
    # oscilloscope.write(":CHANnel3:OFFSet -0.9")            # Subtract 0.9 V by setting an offset of –0.9 V.

    voltagedmm.write('INIT')
    currentdmm.write("TRIG:DIG:STIM EXT")
    time.sleep(0.1)
    
    # voltagedmm.write("*TRIG")
    # currentdmm.write("*TRIG")
    trigpin.off()

def PowerMeasureRead():
    trigpin.on()
    time.sleep(0.1) # Wait the data becomes ready to read
    # DMM7510
    print("CURRENT READ")
    currentdmm.query("*OPC?")
    currentdmm.write("FORM REAL")
    currentdmm.write('TRAC:DATA? 1, '+str(currentsample)+', "defbuffer1", READ')
    currentdata = currentdmm.read_binary_values(datatype = 'd', is_big_endian = False, data_points=currentsample)

    #34465A
    # currentdmm.write('FORM:DATA REAL,64')  # 転送フォーマットはBINARY
    # currentdmm.write('FETC?')  # 測定値の転送
    # currentdata = currentdmm.read_binary_values(datatype = 'd', is_big_endian = True, data_points=currentsample)
    print("VOLT READ")
    voltagedmm.query('*OPC?')
    voltagedmm.write('FORM:DATA REAL,64')  # 転送フォーマットはBINARY
    voltagedmm.write('DATA:REM? '+str(voltagesample))  # 測定値の転送
    # voltagedmm.write('FETC?')  # 測定値の転送
    # read_binary_values(datatype = 'd', ) は、float型 の list を返す
    voltdata = voltagedmm.read_binary_values(datatype = 'd', is_big_endian = True,data_points=voltagesample)
    if(max(voltdata) >= 1.2):
        print("VOLTAGE PROTECTION!")
        turnoff()
        exit(1)
    print("MIN VOL:" + str(min(voltdata)))
    print("MAX VOL:" + str(max(voltdata)))
    print("MAX CURR:" + str(max(currentdata)))
    print("MIN CURR:" + str(min(currentdata)))
    import numpy as np

    # Number of current samples
    n_current = len(currentdata)

    # The time indices for the current data.
    # We assume the current sample interval is dt (unknown, but cancels out) and the voltage sample interval is 5*dt.
    # So the current time points can be considered as: 0, 1, 2, ..., n_current-1
    t_current = np.arange(n_current)

    # Voltage is sampled 5 times slower.
    # Therefore, the voltage samples are at times: 0, 5, 10, ... up to len(voldata)*5 - 5.
    t_voltage = np.arange(len(voltdata)) * sampleratio

    # Interpolate the voltage values at each current time index.
    vol_interp = np.interp(t_current, t_voltage, voltdata)

    # Calculate power at each current sample: P = I * V.
    power = np.array(currentdata) * vol_interp
    # print([ float(x) for x in currentdmm.query(':TRAC:DATA? 1, 200, "defbuffer1"')[:-1].split(",")])
    # print(currentdmm.query(':TRAC:DATA? 1, 100, "defbuffer1", READ'))
    print("POWER:"+str(max(power)))
    return max(power), (voltdata, currentdata, power)

def xoshirotest(userefclk = True):
    if userefclk:
        spireset()
        spiconf.bits_per_word = 8

        ret = spiconf.xfer(8*[0x00])
        spiconfdummy.bits_per_word = 8
        ret = spiconfdummy.xfer(9*[0x00])
    ctrlcs.off()
    spictrl.bits_per_word = 15
    ret = spictrl.xfer([reverse_byte(cmd_seed),0x00]) #init async queue
    spictrl.bits_per_word = 8
    with open("testvectors/asconseed0.tv") as f:
        for s_line in f.read().splitlines():
            seedbytes = [reverse_byte(int(s_line[x:x+2],16)) for x in range(0, len(s_line), 2)]
            seedbytes.reverse()
            spictrl.xfer(seedbytes)
    with open("testvectors/asconseed1.tv") as f:
        for s_line in f.read().splitlines():
            seedbytes = [reverse_byte(int(s_line[x:x+2],16)) for x in range(0, len(s_line), 2)]
            seedbytes.reverse()
            spictrl.xfer(seedbytes)
    with open("testvectors/xoshiroseed.tv") as f:
        for s_line in f.read().splitlines():
            seedbytes = [reverse_byte(int(s_line[x:x+2],16)) for x in range(0, len(s_line), 2)]
            seedbytes.reverse()
            spictrl.xfer(seedbytes)
    ctrlcs.on()
    time.sleep(0.001)

    ctrlcs.off()
    spictrl.bits_per_word = 15
    ret = spictrl.xfer([0x00,0x00]) #init async queue
    spictrl.bits_per_word = 8
    ret = spictrl.xfer([reverse_byte(cmd_infifo)])
    with open("testvectors/input.tv") as f:
        for s_line in f.read().splitlines():
            s_filled = s_line.zfill(8)
            inputbytes = [reverse_byte(int(s_filled[x:x+2],16)) for x in range(0, len(s_filled), 2)]
            inputbytes.reverse()
            spictrl.xfer(inputbytes)
    ret = spictrl.xfer([0x00]) #make sure that the transfer will end correctly
    ctrlcs.on()
    time.sleep(0.001)

    diffcounter.write("INITiate")
    time.sleep(0.1) #needs time before trigger works

    ctrlcs.off()
    spictrl.bits_per_word = 15

    PowerMeasureStart()
    
    start = time.time()
    ret = spictrl.xfer([reverse_byte(cmd_run),0x00]) #init async queue

    ctrlcs.on()
    print("WAITING FIN")
    while True:
        if finpin.value:
            break
    end = time.time()
    print("DONE")
    time_diff = end - start
    print("by polling")
    print(time_diff)
    print("by triggering")
    time_diff=diffcounter.query("FETCh?")
    print(time_diff)

    power, dmmdata = PowerMeasureRead()

    ctrlcs.off()
    spictrl.bits_per_word = 15
    ret = spictrl.xfer([0x00,0x00]) #init async queue
    spictrl.bits_per_word = 8
    ret = spictrl.xfer([reverse_byte(cmd_out)])
    time.sleep(0.001)
    spictrl.bits_per_word = 32
    with open("testvectors/compress_output.tv") as f:
        for s_line in f.read().splitlines():
            ret = spictrl.xfer([0x00,0x00,0x00,0x00])
            s_filled = s_line.zfill(8)
            expectedbytes = [reverse_byte(int(s_filled[x:x+2],16)) for x in range(0, len(s_filled), 2)]
            if ret != expectedbytes:
                print(ret)
                print(expectedbytes)
            assert(ret == expectedbytes)
    print("XOSHIROTEST PASS")
    return [power, time_diff, dmmdata]

def precisetest():
    global bkraintt_bytes
    if bkraintt_bytes == []:
        print("Reading BK")
        with open('testvectors/bk.pickle', mode='br') as fi:
            bkraintt_bytes = pickle.load(fi)
    spireset()
    spiconf.open(1,2)
    spiconf.max_speed_hz = spifreq
    spiconf.mode = 0b00
    spiconf.bits_per_word = 8
    config_str = str(hex(0b00000000_0000000_00000000_0000_0000_0000000000_000_0_0_0_0_0_111_0))[2:].zfill(16)
    config_bytes = [reverse_byte(int(config_str[x:x+2],16)) for x in range(0, len(config_str), 2)]
    config_bytes.reverse()
    ret = spiconf.xfer(config_bytes)
    spiconf.open(1,1)
    spiconf.max_speed_hz = spifreq
    spiconf.mode = 0b00
    spiconf.bits_per_word = 8
    ret = spiconf.xfer(9*[0x00])

    ctrlcs.off()
    spictrl.bits_per_word = 15
    ret = spictrl.xfer([reverse_byte(cmd_infifo),0x00]) #init async queue
    spictrl.bits_per_word = 8
    with open("testvectors/input.tv") as f:
        for s_line in f.read().splitlines():
            s_filled = s_line.zfill(8)
            inputbytes = [reverse_byte(int(s_filled[x:x+2],16)) for x in range(0, len(s_filled), 2)]
            inputbytes.reverse()
            spictrl.xfer(inputbytes)
    ret = spictrl.xfer([0x00]) #make sure that the transfer will end correctly
    ctrlcs.on()
    time.sleep(0.001)


    nindex = 0
    while(nindex < lvl0n):
        print(nindex)
        PowerMeasureStart()
        for k in range(lvl1k+1):
            ctrlcs.off()
            spictrl.bits_per_word = 15
            ret = spictrl.xfer([0x00,0x00]) #init async queue
            spictrl.bits_per_word = 8
            ret = spictrl.xfer([reverse_byte(cmd_bkfifo[k])])
            spictrl.bits_per_word = wordbits-1
            for i in range(nindex,nindex+nstep):
                    for kindex in range(lvl1k+1):
                        for l in range(lvl1l):
                            for cycle in range(numcycle):
                                for bus in range(bknumbus//(lvl1k+1)):
                                    for word in range(nttwordsinbus): 
                                        ret = spictrl.xfer(bkraintt_bytes[k][i*(lvl1k+1)*lvl1l*lvl1N + kindex*lvl1l*lvl1N + l*lvl1N + cycle*bknumbus//(lvl1k+1)*nttwordsinbus+bus*nttwordsinbus+word])
            ctrlcs.on()
            time.sleep(0.001)
        ctrlcs.off()
        spictrl.bits_per_word = 15
        ret = spictrl.xfer([reverse_byte(cmd_runstep),0x00]) #init async queue
        spictrl.bits_per_word = 8
        spictrl.xfer([(1<<nstep)-1])
        ret = spictrl.xfer([0x00]) #make sure that the transfer will end correctly
        ctrlcs.on()
        time.sleep(0.001)
        nindex = nindex + nstep
        print("WAITING FIN")
        finpin.wait_for_active()
        PowerMeasureRead()
    print("DONE")


    ctrlcs.off()
    spictrl.bits_per_word = 15
    ret = spictrl.xfer([0x00,0x00]) #init async queue
    spictrl.bits_per_word = 8
    ret = spictrl.xfer([reverse_byte(cmd_out)])
    time.sleep(0.001)
    spictrl.bits_per_word = 32
    with open("testvectors/precise_output.tv") as f:
        for s_line in f.read().splitlines():
            ret = spictrl.xfer([0x00,0x00,0x00,0x00])
            s_filled = s_line.zfill(8)
            expectedbytes = [reverse_byte(int(s_filled[x:x+2],16)) for x in range(0, len(s_filled), 2)]
            assert(ret == expectedbytes)

    print("PRECISE TEST PASS")

def setPLL(PLLCOARSEDELAYBINARY_CODE, PLLMMDCLKDIV_RATIO, PIgain):
    # Initialize Pins
    pllbypasspin.on()
    spireset()

    spiconf.close()
    spiconf.open(1,2)
    spiconf.max_speed_hz = spifreq
    spiconf.mode = 0b00
    spiconf.bits_per_word = 8
    ret = spiconf.xfer(config_bytes(PLLCOARSEDELAYBINARY_CODE, PLLMMDCLKDIV_RATIO, PIgain))
    # ret = spiconf.xfer(8*[0xff])
    spiconf.close()
    spiconf.open(1,1)
    spiconf.max_speed_hz = spifreq
    spiconf.mode = 0b00
    spiconf.bits_per_word = 8
    ret = spiconf.xfer(9*[0x0])
    # print([reverse_byte(x) for x in ret])
    # print(repeat_reconstruct(ret))

    time.sleep(0.02) # Wait for Reset

    spiconf.close()
    spiconf.open(1,2)
    spiconf.max_speed_hz = spifreq
    spiconf.mode = 0b00
    spiconf.bits_per_word = 8
    ret = spiconf.xfer(config_bytes(PLLCOARSEDELAYBINARY_CODE, PLLMMDCLKDIV_RATIO, PIgain,False))
    spiconf.close()
    spiconf.open(1,1)
    spiconf.max_speed_hz = spifreq
    spiconf.mode = 0b00
    spiconf.bits_per_word = 8
    ret = spiconf.xfer(9*[0x0])

    time.sleep(0.5) # Wait Settling

    spiconf.close()
    spiconf.open(1,2)
    spiconf.max_speed_hz = spifreq
    spiconf.mode = 0b00
    spiconf.bits_per_word = 8
    ret = spiconf.xfer(config_bytes(PLLCOARSEDELAYBINARY_CODE, PLLMMDCLKDIV_RATIO, PIgain,False))
    spiconf.close()
    spiconf.open(1,1)
    spiconf.max_speed_hz = spifreq
    spiconf.mode = 0b00
    spiconf.bits_per_word = 8
    ret = spiconf.xfer(9*[0x0])
    if repeat_reconstruct(ret) != config_bytes(PLLCOARSEDELAYBINARY_CODE, PLLMMDCLKDIV_RATIO, PIgain,False):
        print("PLL NOT LOCKED!")
        return False, 0
    else:
        print("PLL LOCKED")

    pllbypasspin.off()
    time.sleep(3)

    icvolt = powersupply.query('MEAS:VOLT? (@1)')
    pllvolt = powersupply.query('MEAS:VOLT? (@2)')
    # print("IC Voltage:" + icvolt)
    # print("PLL Volatage:" + pllvolt)
    # print(powersupply.query('MEAS:CURR? (@2)'))
    if float(icvolt) > 0.8 and float(pllvolt) > 0.8:
        freq=float(freqcounter.query("READ:FREQ?"))*512
        print("Frequency")
        print(str(freq)+"[Hz]")
        print(str(int(round(freq/1e6)))+"[MHz]")
        return True, freq
    else:
        print("IC Voltage:" + icvolt)
        print("PLL Volatage:" + pllvolt)
        raise ValueError("Too much power consumption!")
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

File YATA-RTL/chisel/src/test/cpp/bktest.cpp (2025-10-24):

#include <verilated.h>
#include <verilated_fst_c.h>
#include <VAXISBRWrapper.h>
#include <tfhe++.hpp>

struct xoshiro128{
  std::array<uint32_t,4> s;
  uint32_t result;

  static inline uint32_t rotl(const uint32_t x, int k) {
    return (x << k) | (x >> (32 - k));
  }
  void next(void) {
    result = (rotl(s[1] * 5, 7) * 9)&((1U<<30)-1);

    const uint32_t t = s[1] << 9;

    s[2] ^= s[0];
    s[3] ^= s[1];
    s[1] ^= s[2];
    s[0] ^= s[3];

    s[2] ^= t;

    s[3] = rotl(s[3], 11);
  }
};

//allgned to distribute to module
constexpr int radixbit = 3;
constexpr int radix = 1<<radixbit;
constexpr int nttsize = 64;
constexpr uint numcycle = 8;
constexpr int interslr = 8;

constexpr uint fiber = TFHEpp::lvl1param::n/numcycle;
constexpr uint bknumbus = 12;
constexpr uint buswidthlb = 9;
constexpr uint buswidth = 1<<buswidthlb;
constexpr uint buswords = 1U<<(buswidthlb-5);
constexpr uint wordsinbus = (1U<<buswidthlb)/std::numeric_limits<typename TFHEpp::lvl0param::T>::digits;
constexpr uint nttwordsinbus = (1U<<buswidthlb)/32;
constexpr uint alignedlenlvl0 = (((std::numeric_limits<TFHEpp::lvl0param::T>::digits*(TFHEpp::lvl0param::n+1)>>buswidthlb)+1)<<buswidthlb)/std::numeric_limits<TFHEpp::lvl0param::T>::digits;
constexpr uint alignedlenlvl1 = (((std::numeric_limits<TFHEpp::lvl1param::T>::digits*(TFHEpp::lvl1param::n+1)>>buswidthlb)+1)<<buswidthlb)/std::numeric_limits<TFHEpp::lvl1param::T>::digits;
constexpr uint trlwenumbus = nttsize/wordsinbus;

constexpr uint numprng = buswidth/32;

constexpr uint8_t cmd_seed = 0b10100000;
constexpr uint8_t cmd_infifo = 0b10110000;
constexpr uint8_t cmd_run = 0b11110000;
constexpr uint8_t cmd_runstep = 0b11100000;
constexpr uint8_t cmd_flush = 0b11000000;
constexpr std::array<uint8_t,3> cmd_bkfifo = {0b10101100,0b10101101,0b10101110};
constexpr uint8_t cmd_out = 0b10000000;
constexpr uint8_t nstep = 2;
constexpr uint8_t spibuswidth = 2;
using alignedTLWElvl0 = std::array<TFHEpp::lvl0param::T,alignedlenlvl0>;
using alignedTLWElvl1 = std::array<TFHEpp::lvl1param::T,alignedlenlvl1>;

constexpr uint asyncqueueinit = 8;

alignas(4096) std::array<std::array<std::array<std::array<std::array<uint32_t,nttwordsinbus>,numcycle>,(TFHEpp::lvl1param::k+1)*TFHEpp::lvl1param::l>,TFHEpp::lvl0param::n>,bknumbus> bkrainttaligned = {};
std::array<uint,bknumbus> buscycle = {};

static uint64_t time_counter = 0;

void clock(VAXISBRWrapper *dut, VerilatedFstC* tfp){
  dut->eval();
  tfp->dump(1000*time_counter);
  time_counter++;
  dut->clock = !dut->clock;
  dut->eval();
  tfp->dump(1000*time_counter);
  time_counter++;
  dut->clock = !dut->clock;
}


void spiclock(VAXISBRWrapper *dut, VerilatedFstC* tfp){
  constexpr uint clockratio = 3;
  for(int i = 0; i < clockratio; i++) clock(dut,tfp);
  dut->io_controlSPI_SCLK = !dut->io_controlSPI_SCLK;
  for(int i = 0; i < clockratio; i++) clock(dut,tfp);
  dut->io_controlSPI_SCLK = !dut->io_controlSPI_SCLK;
}

int main(int argc, char** argv) {
  //generatros
  std::random_device seed_gen;
  std::default_random_engine engine(seed_gen());
  std::uniform_int_distribution<uint32_t> binary(0, 1);
  std::uniform_int_distribution<uint32_t> bubble(0, 100);
  std::uniform_int_distribution<uint32_t> seedgen(0, std::numeric_limits<uint32_t>::max());
  
  //Initialize TFHEpp objects
  TFHEpp::SecretKey *sk = new TFHEpp::SecretKey();
  TFHEpp::BootstrappingKeyRAINTT<TFHEpp::lvl01param> *bkraintt = new TFHEpp::BootstrappingKeyRAINTT<TFHEpp::lvl01param>();
  TFHEpp::bkrainttgen<TFHEpp::lvl01param>(*bkraintt,*sk);
  for(int i = 0; i < TFHEpp::lvl0param::k*TFHEpp::lvl0param::n; i++) for(int l = 0; l < TFHEpp::lvl1param::l*(TFHEpp::lvl1param::k+1);l++) for(int k = 0; k < TFHEpp::lvl1param::k+1; k++) for(int j = 0; j < TFHEpp::lvl1param::n; j++)
    (*bkraintt)[i][l][k][j] = ((*bkraintt)[i][l][k][j] % raintt::P + raintt::P) % raintt::P;

  Verilated::commandArgs(argc, argv);
  VAXISBRWrapper *dut = new VAXISBRWrapper();

  Verilated::traceEverOn(true);
  VerilatedFstC* tfp = new VerilatedFstC;
  dut->trace(tfp, 100);  // Trace 100 levels of hierarchy
  tfp->open("simx.fst");

  std::array<std::array<xoshiro128,numprng>,bknumbus> prngs;
  for(int i = 0; i < bknumbus; i++){
    for(int j = 0; j < numprng; j++){
      for(int k = 0; k < 4; k++){
        prngs[i][j].s[k] = seedgen(engine);
      }
    }
  } 

  // Format
  dut->reset = 1;
  dut->clock = 0;
  dut->io_compress = (1<<4)-1;
  // dut->io_compress = 0;
  dut->io_controlSPI_SS = 1;
  dut->io_controlSPI_MOSI = 0;
  dut->io_controlSPI_SCLK = 0;

  // Reset
  clock(dut, tfp);

  //Release reset
  dut->reset = 0;

  for(int _ = 0; _ < 2; _++){

  std::cout<<"Initialize"<<std::endl;
  std::cout<<"BK Init"<<std::endl;
  for(int k = 0; k < TFHEpp::lvl1param::k+1; k++){
  std::cout<<k<<std::endl;
  dut->io_controlSPI_SS = 0;
  for(int i = 0; i < asyncqueueinit; i++) spiclock(dut, tfp);
  for(int i = 0; i < 8/spibuswidth; i++){
    dut->io_controlSPI_MOSI = (cmd_bkfifo[k]>>(i*spibuswidth))&((1<<spibuswidth)-1);
    spiclock(dut, tfp);
  }
  for(int i = 0; i < nstep; i++) for(int l = 0; l < TFHEpp::lvl1param::l; l++) for(int kindex = 0; kindex <= TFHEpp::lvl1param::k; kindex++) for(int cycle = 0; cycle < numcycle; cycle++) for(int bus = 0; bus < bknumbus/(TFHEpp::lvl1param::k+1); bus++) for(int word = 0; word<nttwordsinbus; word++) 
  for(int bit = 0; bit < (raintt::wordbits-1)/spibuswidth; bit++){
    dut->io_controlSPI_MOSI = ((*bkraintt)[i][kindex*TFHEpp::lvl1param::l+l][k][cycle*bknumbus/(TFHEpp::lvl1param::k+1)*nttwordsinbus+bus*nttwordsinbus+word]>>(bit*spibuswidth))&((1<<spibuswidth)-1);;
    spiclock(dut, tfp);
  }
  dut->io_controlSPI_MOSI = 0;
  for(int i = 0; i < 8; i++) clock(dut, tfp);
  dut->io_controlSPI_SS = 1;
  for(int i = 0; i < asyncqueueinit; i++) clock(dut, tfp);
  std::cout<<"bk:"<<std::hex<<static_cast<uint64_t>((*bkraintt)[0][0][k][0])<<std::endl;
  }
  
  alignedTLWElvl0 alignedcin = {};
  bool p = (binary(engine) > 0);
  const TFHEpp::TLWE<TFHEpp::lvl0param> tlwe = TFHEpp::tlweSymEncrypt<TFHEpp::lvl0param>(p,TFHEpp::lvl0param::α,sk->key.lvl0);
  for(int i = 0; i <= TFHEpp::lvl0param::n; i++) alignedcin[i] = tlwe[i];
  TFHEpp::Polynomial<TFHEpp::lvl1param> testvec;
  for (int i = 0; i < TFHEpp::lvl1param::n; i++)
      testvec[i] = TFHEpp::lvl1param::μ;

  TFHEpp::TRLWE<TFHEpp::lvl1param> trlwe, resaligned;
  trlwe = {};
  const uint32_t b̄ =
        2 * TFHEpp::lvl1param::n - (tlwe[TFHEpp::lvl0param::n] >>(std::numeric_limits<typename TFHEpp::lvl0param::T>::digits - 1 - TFHEpp::lvl1param::nbit) );
  TFHEpp::PolynomialMulByXai<TFHEpp::lvl1param>(trlwe[TFHEpp::lvl1param::k],TFHEpp::μpolygen<TFHEpp::lvl1param,TFHEpp::lvl1param::μ>(),b̄);
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

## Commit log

2025-10-24 Add the version prepared for review
    [BOM-YATA-PCB.csv, CPPLINT.cfg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]
2025-10-25 Add README for PCB
    [CPPLINT.cfg]
2025-10-30 Fix typo in README.md regarding sense resistor
2025-11-20 Insert newline for readability
